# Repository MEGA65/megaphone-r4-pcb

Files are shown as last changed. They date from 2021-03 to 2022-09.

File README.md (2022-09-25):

# megaphone-pcb-2020

This repository contains the PCB design for the MEGAphone R4 board.

This work was supported by the NLnet Foundation under https://nlnet.nl/project/Mega65/, for which we are extremely grateful. With their support we are very pleased to make these designs available on an open-source basis under the GPLv3.

# Why make an 8-bit Smart-Phone in 2022?

Much of the insecurity and lack of privacy is the simple result of how complex computers, the internet and all of the protocols and technologies that they include. It seems that the majority of proposals to fix this solution consist of adding something to this complicated mess. While this has helped to reduce the symptoms of the problem, by adding complexity it has actually made the problem worse. There are simply too many places for insecurities and privacy violating software to hide in modern complex systems. Even the hardware itself is not immune, with problems like SPECTRE, MELTDOWN and vulnerabilities in the management processors of modern computers and phones showing that even the processors we use today carry significant risks due to their complexity. This project takes a contrarian approach of seeing just how simple a system can be make, that would still be useful for a core set of functionality. The project takes inspiration from the simple and effective computers of the 1980s: it explores how to retain their simplicity and transparency, and combine them with modern improvements in security and capability. The goal is to allow even a single determined person to completely verify that a device has not been compromised, and that there are no unwanted listening ears when performing privacy sensitive tasks. The project will advance its current proof-of-concept to a functioning hardware and software system that can demonstrate profoundly improved security and privacy, and in a way that allows a determined user to verify that the device is still truly under their exclusive control and serving them alone.

# What about FPGA bitstreams and software to run on it?

See https://github.com/mega65 and https://github.com/mega65/mega65-core in particular.  The MEGAphone is designed to be software compatible with the MEGA65 retro computer. In fact, the MEGA65 can be used as a development target, as it lacks only the cellular modems and touch interface. We will likely make a development board that can connect to a MEGA65 to allow connection of cellular modems, and maybe even a touch screen interface, to ease cross-development in this way.

# Focus of the R4 PCB Changes

The focus of this iteration of the PCB design was to get the power management system implemented, so that the device can charge its own battery from mains, USB, a car 12V accessory outlet or a solar panel. This will also allow the inclusion of a solar panel in the device, thus allowing it to in theory have infinite battery life / energy self-sufficiency, which would be very helpful for people living in isolated areas, or where power is unreliable for various reasons.

Other significant changes are the inclusion of a place for a Pi Compute Module 4, so that Android can be run in a secure sand-box, if required, and a general reworking to reduce the outline size of the PCB somewhat.  Support has also been added for various add-on modules for backup communications channels, as well as moving the audio circuitry to a pluggable module, so that Bluetooth and audio amplifiers and filters can be iterated separately from the rest of the PCB.

# Prototype MEGAphone R4

The PCB design in this repo has been built and initial hardware bring-up has been performed, confirming that the power system works.  A bunch of errata have been identified in the process, which are tracked in the issues of this repository.  The board currently looks like this:

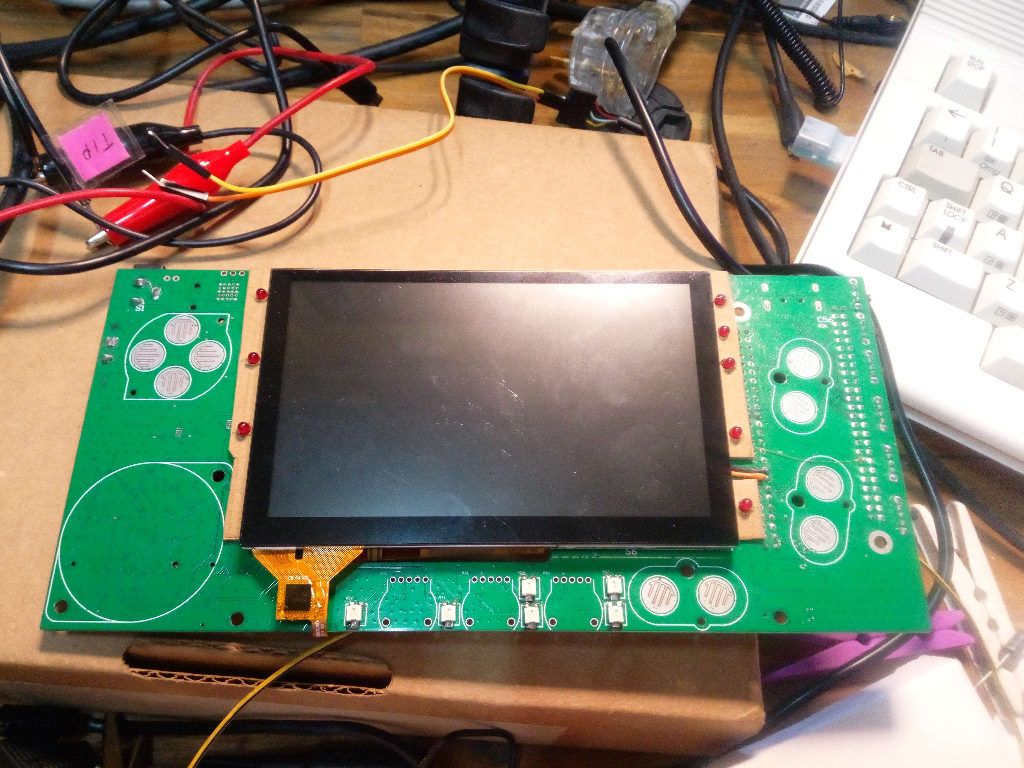
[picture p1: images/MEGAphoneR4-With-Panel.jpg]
Front of MEGAphone R4 PCB, with LCD panel fitted


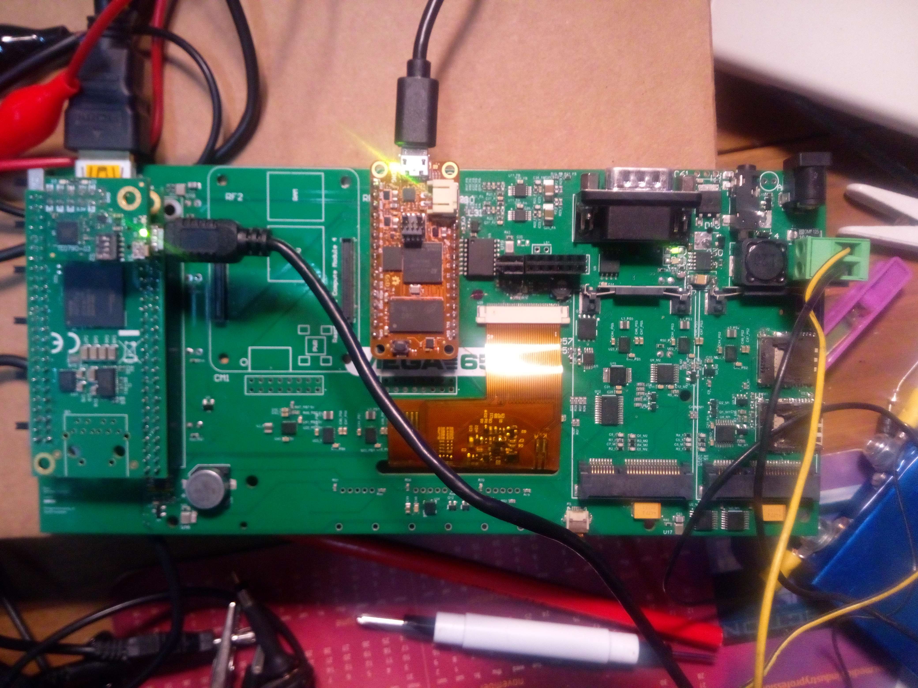
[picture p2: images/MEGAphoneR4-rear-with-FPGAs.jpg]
Rear of MEGAphone R4 PCB, with TE0725 and OrangeCrab FPGA modules fitted


Note that the VGA connector of the R2 has been replaced with the same connector as HDMI to allow digital video. It and the joystick port
(which also doubles as a general accessory connector) have both been pulled back within the rectangular outline. This makes the complete device noticeably smaller than the R2 which had protrusions on opposite corners to support the VGA and joystick connectors.

There are also 3 16-pin headers, two for UHF packet radios or other communications accessories, linked by UARTs to the OrangeCrab FPGA, and one that also has audio signals routed to it, so that it can host WiFi, Bluetooth and audio amplifier circuits. This audio module port was
added to save space on the main PCB, to make room for the relocated connectors, and the Raspberry Pi CM4 that can be used to run Android applications or other "heavy" computations in a sand-box that is isolated from the simple 8-bit environment that runs on the Xilinx FPGA.

The OrangeCrab FPGA module is an important addition, as it supports the power management system, allowing various power rails to be turned on and off, and also buffers serial communications from the two cellular modem/alternative communications bays, as well as the two 16-pin headers provided for packet radios or other communications modules.  This allows the main Xilinx FPGA to be powered off most of the time, thus enabling longer battery life.

The R4 PCB also finally has battery charging circuitry that can charge the 1S LiFePO4 cell, using any source from ~5V to ~20V, including automotive 12V accessory connector, USB power or a solar panel.  A solar panel will be fitted to the prototypes when fully assembled, thus allowing full energy autonomy in most cases.

# Companion Blog Posts

* https://c65gs.blogspot.com/2020/06/ultrasonic-communications-for-mega65.html
* https://c65gs.blogspot.com/2020/10/megaphone-r2-hardware-bringup.html
* https://c65gs.blogspot.com/2020/11/megaphone-pcb-changes.html
* https://c65gs.blogspot.com/2021/06/megaphone-pcb-re-spin.html
* https://c65gs.blogspot.com/2022/09/megaphone-r4-pcb-bring-up-part-1.html
* https://c65gs.blogspot.com/2022/09/megaphone-r4-pcb-bring-up-part-2.html
* https://c65gs.blogspot.com/2022/09/megaphone-r4-pcb-bring-up-part-3.html

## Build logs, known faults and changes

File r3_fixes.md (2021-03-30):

## R3

### Fixing DPAD size 

Fixed the position and markings of the D-PAD, including orientation holes (ERRATA#28).
Replaceed the two small thin black buttons with another pair of round pads, as described in the blog post (ERRATA#29).
Swaped the function of the existing pair of round pads and the two thin black buttons (ERRATA#30).

https://github.com/MEGA65/megaphone-pcb-2020/issues/20

### Replace VGA with HDMI-compatible interface #13

Useed the HDMI circuit design from the MEGA65 R3 PCB schematic to implement HDMI, freeing up a number of pins (ERRATA#4).
To verify that the necessary signal integrity is possible via the standard .1” IDC headers we created small main board for TE0725 that can hold PMOD boards. We have made changes to existing PMOD so we can use TMDS signals. After few unsucesfull atempts we managed to get HDMI working.
Main problem was that for some reason serialiser from Mega65 HDMI did not work. So we tryed with simple DVI sample from ULX3S, and that worked. 

Replaced VGA interface with HDMI interface based off the MEGA65 R3 PCB (ERRATA#4).

https://github.com/MEGA65/megaphone-pcb-2020/issues/13

### LCD

Removeed the currently routed 6-pin FLC connector for the touch panel, and the 6-pin FLC connector near the bottom of the PCB, but not the one nearest the bottom of the PCB, which is to be retained (ERRATA#5).
Removed the smaller of the two slot-holes in the PCB, and the two extra 6-pin FLC connectors to free up some PCB space (ERRATA#29). This will be somewhat offset by having to route the I2C lines further to get to the connector’s new position.
Moved the remaining 6-pin touch panel digitiser connector 2mm in the direction of the D-SUB9 joystick port (ERRATA#3).
Moved the 40-pin LCD panel connector 10mm further towards the top of the board (ERRATA#1).

https://github.com/MEGA65/megaphone-pcb-2020/issues/9

### Pin swapping

Swaped pins 1 and 3 of S7, so that the "on" position is "on under control of the power control circuit" and "off" is truly off (ERRATA#39).

https://github.com/MEGA65/megaphone-pcb-2020/issues/7

### Transmitters

For regulatory purposes, it is desirable for the main PCB to not be an “intentional transmitter”, that FCC/EC etc approvals are greatly simplified. 
Wifi, lora, BT moved from the board.
Moving the WiFi and BT modules from the main PCB to mezannines
Instead of having wifi and BT separated in R3 we can use ESP32 that offers both with one module.

### CM4

Use CM4, which uses mezannine connectors instead of SODIMM, and takes less space.
Route the parallel video (DPI) interface GPIOs to the main FPGA (requires doing #30 and #13 to free up enough pins on the main FPGA. There should be enough for at least 5 bits per RGB channel, plus HSYNC, VSYNC and DE).
Currently we only added CM4 connectors so we can check if everything will fit.

https://github.com/MEGA65/megaphone-pcb-2020/issues/31
https://github.com/MEGA65/megaphone-pcb-2020/issues/24
https://github.com/MEGA65/megaphone-pcb-2020/issues/2

### POT-X/Y and DSUB

POT-X/Y circuitry copyed from the MEGA65 R3 PCB (ERRATA#17)
Allowed the FIRE line of the joystick port to be controlled and read at high-speed, by using 2 FPGA pins: one to read the level-converted FIRE input, and the other to control a transistor that can be used to pull the 5V side of the FIRE pin to GND when activated. Retain the existing connection to the I2C IO expander (ERRATA#18).
Moveed the D-SUB9 connector to the approximate position of U24, so that it can fit in the main rectangular outline of the PCB (ERRATA#19).

https://github.com/MEGA65/megaphone-pcb-2020/issues/19

### PCB outline

PCB outline returned to the main rectangle, removing the extensions for the D-SUB connectors (ERRATA#20).

### LoRa

Replaceed the on-board LoRa radios with a single header connector that can be used to connect an arbitrary packet radio module (ERRATA#12). 
This connector is compatible with the RFD900 packet UHF radio.

https://github.com/MEGA65/megaphone-pcb-2020/issues/11

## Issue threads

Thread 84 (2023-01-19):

SIM SD card pins are shorted on schematics

goran-mahovlic, 2023-01-19:

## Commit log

2020-12-12 Adding megaphone-r2
    [4G Modem.SchDoc, Audio.SchDoc, Battery.SchDoc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]
2020-12-12 Adding BSS138
    [Power Control.SchDoc]
2020-12-12 Sugested fixes for #12 should also partialy fix #22
    [I2C Expanders.SchDoc, MEGAphone.PrjPcb, Power Control.SchDoc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]
2020-12-12 Invert S7 partially fixing #7
    [Power Control.SchDoc]
2020-12-14 Removing SMART CARD from schematics
    [SD & SMART CARD.SchDoc]
2020-12-14 Setting 5V output to be output
    [PowerSupply5V.SchDoc]
2020-12-14 PCA9535 P pins are IO #29
    [I2C Expanders.SchDoc]
2020-12-14 Setting all FPGA pins as IO
    [FPGA.SchDoc]
2020-12-14 Setting FPGA opendrain pin to IO
    [FPGA.SchDoc]
2020-12-14 Fixing Bluetooth pins direction #29
    [Bluetooth & WIFI.SchDoc]
2020-12-14 Setting SMART CARD pins as NC #29
    [SD & SMART CARD.SchDoc]
2020-12-14 Clearing most of errors - will address others later #29
    [4G Modem.SchDoc, I2C Expanders.SchDoc, MEGAphone Overview.SchDoc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]
2020-12-14 Removing added MIC NET name
    [I2C Expanders.SchDoc, Power Control.SchDoc]
2020-12-14 Anotating MIC enable resistor
    [Power Control.SchDoc]
2020-12-14 Update PBC - fix #4
    [MEGAphone.PrjPcb]
2020-12-15 MIC GND fix
    [Power Control.SchDoc, PowerSupply5V.SchDoc]
2020-12-15 Fixing MIC GND poligon
2020-12-15 Change DPAD to V2
    [I2C Expanders.SchDoc]
2020-12-16 Moving LCD connector by 8mm leaving place for 10mm move #9 d
2020-12-16 Removing P2 and P8 #9 a
    [VGA.SchDoc]
2020-12-16 Removing smaller cut hole #9 b
2020-12-16 Moving Touch connector 2mm #9 c
2020-12-16 Changing S4, Switching S4 and S2 fix #20
    [I2C Expanders.SchDoc, Power Control.SchDoc]
2020-12-16 Adding CM4 as suggested by #31
    [MEGAphone Overview.SchDoc, MEGAphone.PrjPcb]
2020-12-17 Adding TPD and HDMI port #13
    [MEGAphone.PrjPcb, VGA.SchDoc]
2020-12-17 Removing VGA connector and resistor #13
    [VGA.SchDoc]
2020-12-17 Connecting TPD with HDMI connector #13
    [VGA.SchDoc]
2020-12-17 Adding HDMI to board #13
2020-12-19 adding changes to board layout #19 #13
2020-12-19 Removing LoRa from schematics #11 a
    [LoRa Radio.SchDoc]
2020-12-19 Removing BT module from shematic #2
    [Bluetooth & WIFI.SchDoc]
2020-12-19 Removing LoRa and BT from PCB #2 #11
2020-12-19 Big PCB wire cleanup, module move, deletes
2020-12-19 Changing board layout - moving parts
2020-12-21 Adding RFD900 symbol, footpint, 3D model #11
    [LoRa Radio.SchDoc, MEGAphone.PrjPcb, RFD900.SchLib]
2020-12-23 Adding one more RFD900 and fix #7 a
    [LoRa Radio.SchDoc]
2020-12-23 On/off switches positions
2021-02-25 Changing 5V_VCC, MIC_VCC, Adding more FPGA info
    [Audio.SchDoc, FPGA.SchDoc, I2C Expanders.SchDoc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]
2021-02-25 Adding more FPGA info
    [FPGA.SchDoc]
2021-02-25 Adding pin names to FPGA connector
    [FPGA.SchDoc]
2021-03-13 Adding new schematics
2021-03-30 Closer to V3
    [4G Modem.SchDoc, Bluetooth & WIFI.SchDoc, FPGA.SchDoc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]
2021-04-15 Adding pins to CM4 schematics
    [CM4.SchDoc]
2021-04-15 Anotate schematics
    [4G Modem.SchDoc, I2C Expanders.SchDoc, LoRa Radio.SchDoc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]
2021-04-15 project and pcb changes
    [MEGAphone.PrjPcb]
2021-04-21 Connecting CM4 pins
    [CM4.SchDoc, I2C Expanders.SchDoc]
2021-04-21 Connecting CM4 - overview connecting
    [CM4.SchDoc, FPGA.SchDoc, I2C Expanders.SchDoc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]
2021-04-30 Finishing schematics
    [CM4.SchDoc, MEGAphone Overview.SchDoc, Power Control.SchDoc]
2021-04-30 new pdf
    [MEGAphone Overview.SchDoc, MEGAphone.PrjPcb]
2021-05-26 Adding overvew changes
    [I2C Expanders.SchDoc, MEGAphone Overview.SchDoc, Sensors.SchDoc]
2021-05-26 PCB before routing
    [MEGAphone.PrjPcb]
2021-05-26 moving LCD wires
2021-05-30 Fixing errors on schematics
    [4G Modem.SchDoc, CM4.SchDoc, FPGA.SchDoc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]
2021-05-30 Pcb update
2021-11-17 Moved NOR flash to top of the board fix #8
    [FPGA.SchDoc, I2C Expanders.SchDoc, MEGAphone Overview.SchDoc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]
2021-11-17 Adding selection jumper level converter 3V3/1.8V for M2 modems fix #17
    [4G Modem.SchDoc]
2021-11-20 Adding solar charger schematics - Reanotate schematics
    [4G Modem.SchDoc, Audio.SchDoc, Battery.SchDoc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]
2021-11-20 Moving RF1 connector
    [MEGAphone.PrjPcb]
2021-11-22 Adding footprints for Solar charger - update schematics and footprints
    [Lipo_Solar_Charger.SchDoc, RFD900X.SchLib, TO-252AA.PcbLib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]
2021-11-22 Adding updated project files
    [MEGAphone.PrjPcb]
2021-11-23 Adding LiFePO4 charger IC #6
    [Battery.SchDoc, CM4.SchDoc, Lipo_Solar_Charger.SchDoc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]
2021-11-23 Adding IR LED - fix #23
    [FPGA.SchDoc]
2021-11-23 Adding power supply to MUX board #30 #6
    [FPGA_Multiplexer.SchDoc]
2021-11-23 Adding ADC fix #6
    [Battery.SchDoc]
2021-11-23 Battery update
    [Battery.SchDoc]
2021-11-23 Connecting CM4 I2C to FPGA
    [CM4.SchDoc, FPGA.SchDoc]
2022-02-10 Update overvew
    [Battery.SchDoc, FPGA.SchDoc, MEGAphone Overview.SchDoc]
2022-02-10 Cleaning errors in nets
    [4G Modem.SchDoc, Battery.SchDoc, CM4.SchDoc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]
2022-02-10 Clean PCB errors
2022-02-12 All components are on the board
    [4G Modem.SchDoc, Battery.SchDoc]
2022-02-14 Adding GND VIAs
2022-02-17 Routing - removing one capacitor
    [CM4.SchDoc]
2022-02-17 Connecting more GNDs
2022-02-18 Moving audio to #5
    [Audio.SchDoc, Bluetooth & WIFI.SchDoc, FPGA_Multiplexer.SchDoc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]
2022-02-19 Adding schematics change
    [Battery.SchDoc, FPGA.SchDoc]
2022-02-19 Saving all changes
    [4G Modem.SchDoc, Audio.SchDoc, Battery.SchDoc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]
2022-02-21 Adding new schematics pdf
2022-04-02 Initial file save. Libs missing
    The libraries below are missing because they are not bundled with the project. Proceed with caution and readd those libraries to the project.
    - CM4.SchLib
    - CM4.PcbLib
    [MEGAphone.PrjPcb]
2022-04-02 Rule changes
    [MEGAphone.PrjPcb]
2022-04-14 Update PCB
    [MEGAphone.PrjPcb]
2022-04-14 Revert "Update PCB"
    This reverts commit dc219470fc25fcdc6b2688d779228af86c885192.
    [MEGAphone.PrjPcb]
2022-04-14 Route PCB
    [MEGAphone.PrjPcb]
2022-04-18 Routing HDMI
    [MEGAphone.PrjPcb]
2022-05-11 Update PCB Routing (HDMI)
2022-05-12 Squashed commit of the following:
    commit 5d1b474fbe5a729ffc8363ee38d62a312f1cd4cc
    Author: Ivan Fadiga <49251350+ifadiga@users.noreply.github.com>
    Date: Wed May 11 14:54:24 2022 +0200
    Update MEGAphone.PcbDocPreview
    commit ba72847fb4095117463b3f54dd27b1e9e45becd4
    Author: Ivan Fadiga <49251350+ifadiga@users.noreply.github.com>
    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
2022-05-13 Exported production file
    [MEGAphone.PrjPcb]
2022-06-06 Update PCB
    Removed hole from D3
    Changed pin mapping for D3.
    [Battery.SchDoc, MEGAphone.PrjPcb]
2022-08-04 Latest schematics
2022-09-21 rename rear of PCB image
